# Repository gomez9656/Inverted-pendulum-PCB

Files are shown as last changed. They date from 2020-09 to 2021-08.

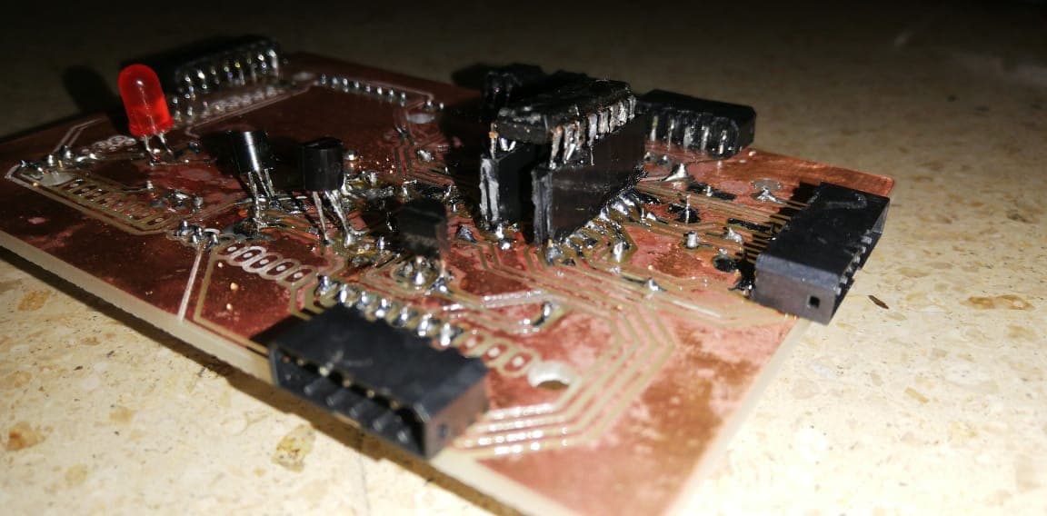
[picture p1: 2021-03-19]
PCB_inverted_pendulum.jpg

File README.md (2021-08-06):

# Inverted-pendulum-PCB
PCB for an inverted pendulum, one layer.

In my college, I had the opportunity to participate in the design of a PCB for an inverted pendulum that used PID control. 

The pendulum used an Arduino Mega that controlled the motors, and my job was to design a PCB shield for the Arduino Mega, so it can be able to fulfill other hardware requirements. I also did a lot of reverse engineering because there were no schematics of the circuit that was working on the pendulum. so it was a very good experience.

I prototyped the PCB shield using an SRM-20 GNC machine, as you can see in the images, the PCB has a lot of components and traces, and I had the requirements to do this in only one layer, so in this way, I can build the prototype very fast using the SRM-20.

In the file section, you can see an image of the board. It is very poor welded(it was my first big project). I was able to prototype it very fast using the Excellon_Gcode, which you can check on my Excellen_Gcode repository.

Don't hesitate to ask me anything if you are looking to do something similar.

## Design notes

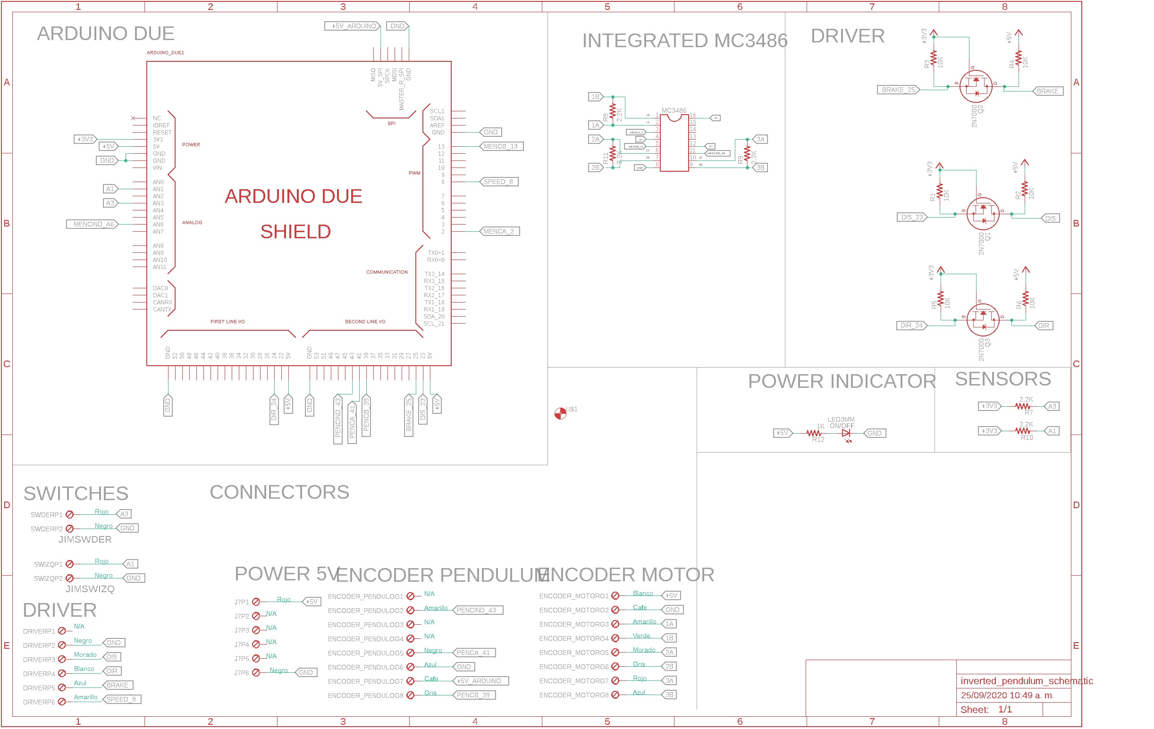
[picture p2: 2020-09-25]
Inverted pendulum/PCB_SCH.png

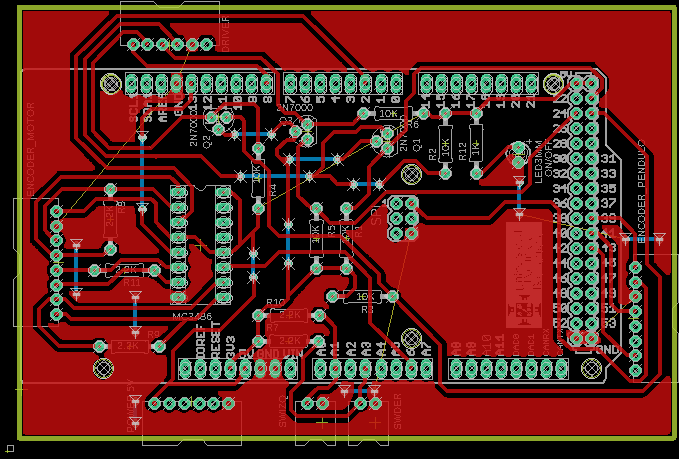
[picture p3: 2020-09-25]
Inverted pendulum/PCB_BOARD.png

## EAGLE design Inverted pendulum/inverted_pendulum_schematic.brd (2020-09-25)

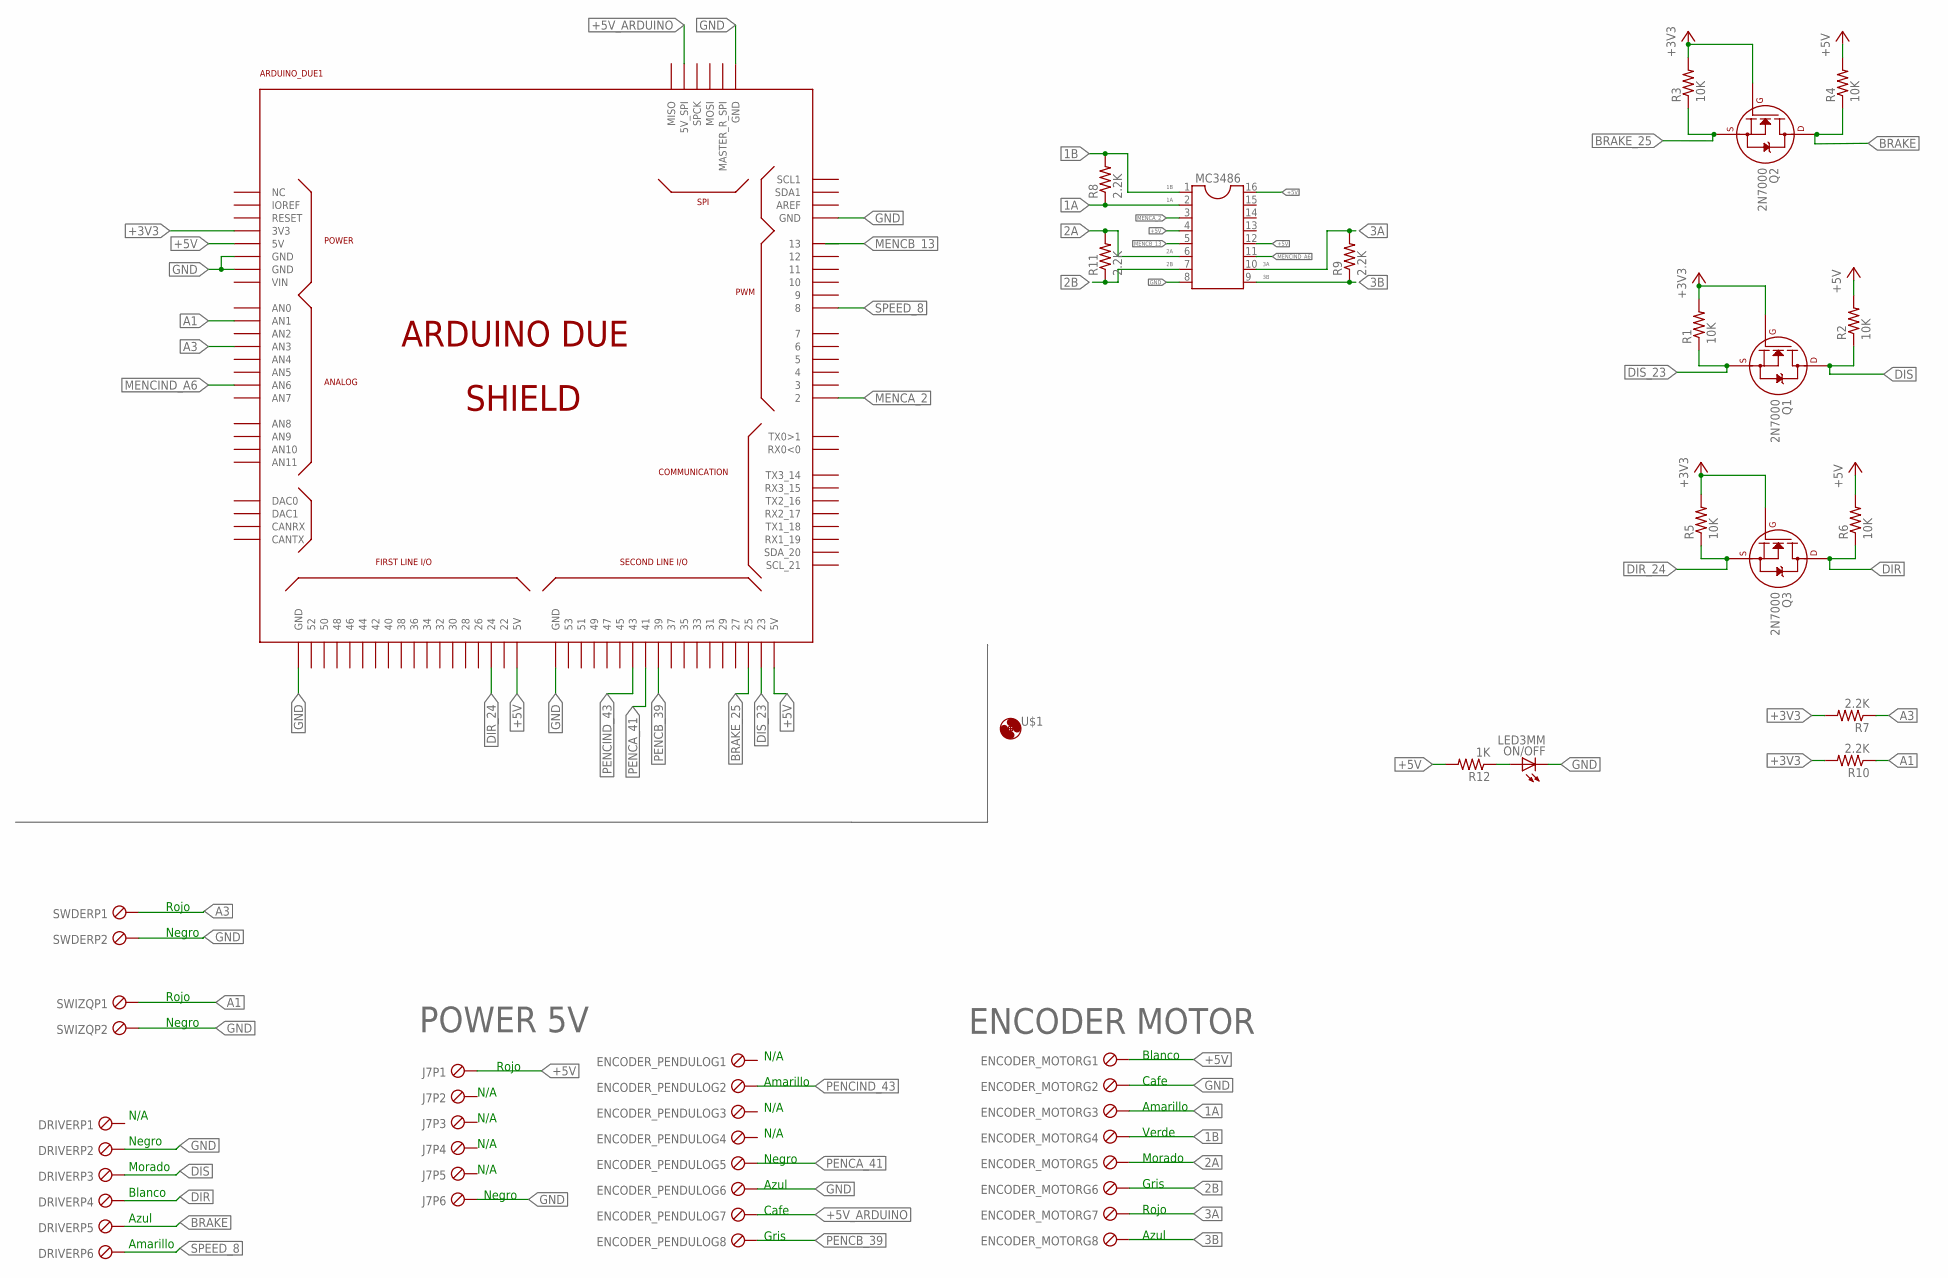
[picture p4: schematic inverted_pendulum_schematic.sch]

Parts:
ARDUINO_DUE1: ARDUINO_DUE_SHIELD
DRIVER: PTSM1/6-2,50_TH; 6PTSMTH
ENCODER_MOTOR: PTSM1/8-2,50_TH; 8PTSMTH
ENCODER_PENDULO: PTSM1/8-2,50_TH; 8PTSMTH
J7: PTSM1/6-2,50_TH; 6PTSMTH
MC3486: DIL16S; SOCKET-16
ON/OFF: LED3MM
Q1, Q2, Q3: 2N7000; TO-92
R1, R2, R3, R4, R5, R6: 10K; 0207/10
R7, R8, R9, R10, R11: 2.2K; 0207/10
R12: 1K; 0207/10
SWDER: PTSM1/2-2,50_TH; 2PTSMTH
SWIZQ: PTSM1/2-2,50_TH; 2PTSMTH
U$1: FIDUCIAL; ROLAND_1

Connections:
1A: ENCODER_MOTOR.P$3, MC3486.2, R8.1
1B: ENCODER_MOTOR.P$4, MC3486.1, R8.2
2A: ENCODER_MOTOR.P$5, MC3486.6, R11.2
2B: ENCODER_MOTOR.P$6, MC3486.7, R11.1
3A: ENCODER_MOTOR.P$7, MC3486.10, R9.2
3B: ENCODER_MOTOR.P$8, MC3486.9, R9.1
+3V3: ARDUINO_DUE1.3V3, Q1.2 (G), Q2.2 (G), Q3.2 (G), R1.2, R3.2, R5.2, R7.2, R10.2
+5V: ARDUINO_DUE1.5V0 (5V), ARDUINO_DUE1.5V0_1 (5V), ARDUINO_DUE1.5V0_2 (5V), ENCODER_MOTOR.P$1, J7.P$1, MC3486.4, MC3486.12, MC3486.16, R2.2, R4.2, R6.2, R12.2
+5V_ARDUINO: ARDUINO_DUE1.5V_2 (5V_SPI), ENCODER_PENDULO.P$7
A1: ARDUINO_DUE1.A1 (AN1), R10.1, SWIZQ.1
A3: ARDUINO_DUE1.A3 (AN3), R7.1, SWDER.1
BRAKE: DRIVER.P$5, Q2.3 (D), R4.1
BRAKE_25: ARDUINO_DUE1.25, Q2.1 (S), R3.1
DIR: DRIVER.P$4, Q3.3 (D), R6.1
DIR_24: ARDUINO_DUE1.24, Q3.1 (S), R5.1
DIS: DRIVER.P$3, Q1.3 (D), R2.1
DIS_23: ARDUINO_DUE1.23, Q1.1 (S), R1.1
GND: ARDUINO_DUE1.GND, ARDUINO_DUE1.GND_1 (GND), ARDUINO_DUE1.GND_2 (GND), ARDUINO_DUE1.GND_3 (GND), ARDUINO_DUE1.GND_4 (GND), ARDUINO_DUE1.GND_5 (GND), DRIVER.P$2, ENCODER_MOTOR.P$2, ENCODER_PENDULO.P$6, J7.P$6, MC3486.8, ON/OFF.K (C), SWDER.2, SWIZQ.2
MENCA_2: ARDUINO_DUE1.2, MC3486.3
MENCB_13: ARDUINO_DUE1.13, MC3486.5
MENCIND_A6: ARDUINO_DUE1.A6 (AN6), MC3486.11
unnamed: ON/OFF.A, R12.1
PENCA_41: ARDUINO_DUE1.41, ENCODER_PENDULO.P$5
PENCB_39: ARDUINO_DUE1.39, ENCODER_PENDULO.P$8
PENCIND_43: ARDUINO_DUE1.43, ENCODER_PENDULO.P$2
SPEED_8: ARDUINO_DUE1.8, DRIVER.P$6

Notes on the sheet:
Azul
Rojo
Gris
Morado
Verde
Amarillo
Cafe
Blanco
N/A
Negro
ENCODER MOTOR
POWER 5V

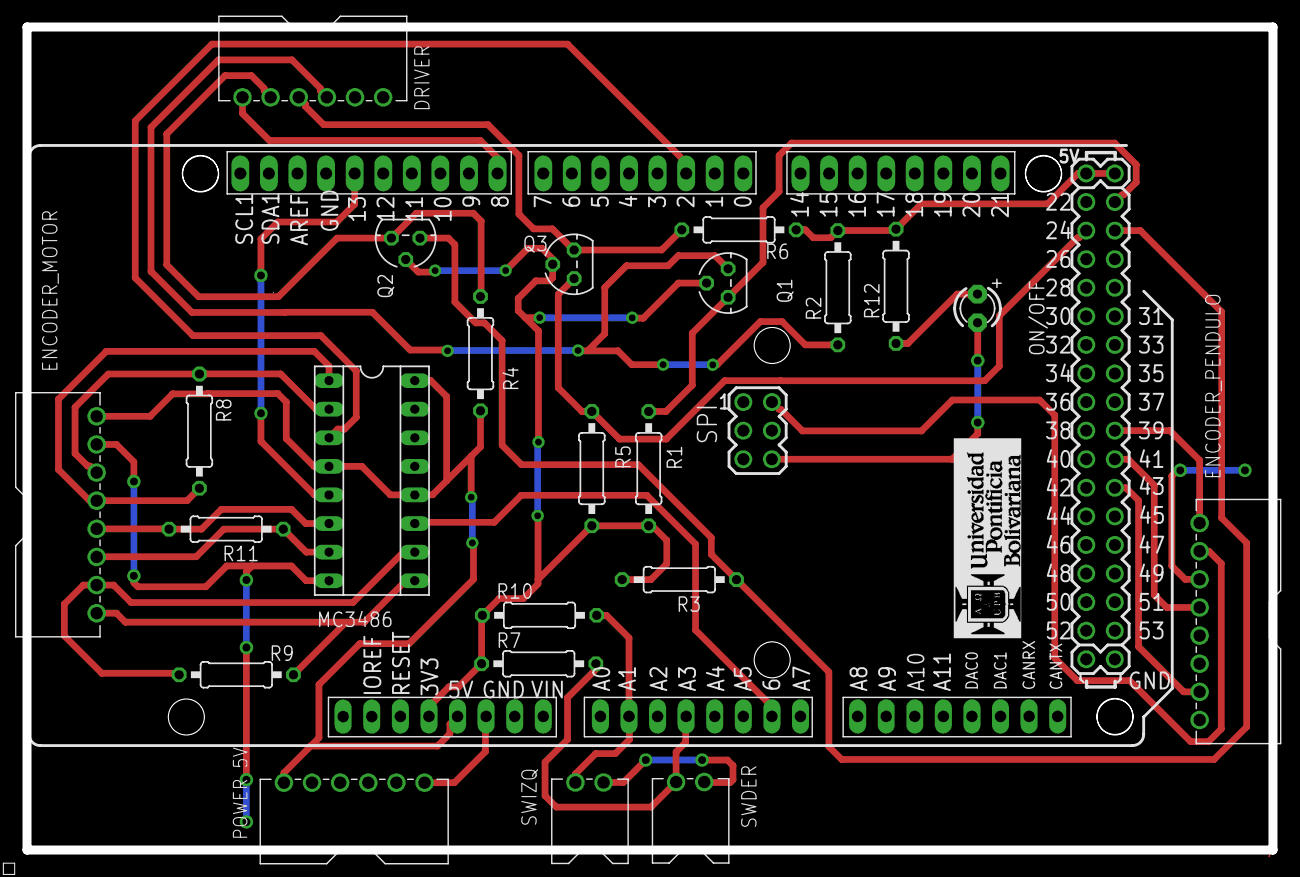
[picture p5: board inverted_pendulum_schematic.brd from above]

Board: 2 copper layers, 110.7 x 73.2 mm, 25 parts (0 on the bottom side), 26 nets.
